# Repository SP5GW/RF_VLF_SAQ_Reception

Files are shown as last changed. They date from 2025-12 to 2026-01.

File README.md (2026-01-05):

<p align="center">

</p> 

# **Odbiór sygnału radiostacji VLF SAQ, Grimeton 17.2 kHz.**

# Wprowadzenie
Pomysł przeprowadzenia odbioru sygnału emitowanego przez szwedzką stację SAQ nadającą spod Geteborga pojawił się przed ponad rokiem. Gdy pierwsza próba odbioru z wykorzystaniem anteny aktywnej miniwhip zakończyła się niepowodzeniem, postanowiłem spróbować ponownie, ale tym razem wykorzystując przedwzmacniacz opisany na stronach Towarzystwa Przyjaciół Grimeton SAQ [1] w połączeniu z anteną magnetyczną.
Wyniki tego eksperymentu oraz wyzwania przed jakimi stanąłem w trakcie jego realizacji opisałem w poniższym artykule.
Źródłem inspiracji do ponownego zmierzenia się z problematyką odbioru sygnałów VLF (Very Low Frequencies) oraz cennych uwag w trakcie przygotowań był kolega Jacek Lipkowski, SQ5BPF. Dziękuję Jacku!

# Antena

## Konstrukcja Anteny

<p align="center">


</p>

*Zdjęcia 1,2: Konstrukcja mechaniczna anteny pętlowej. Indukcyjność anteny to 24.7mH a nie tak jak na rysunku 24.7nH!*

Podczas pierwszej próby odbioru sygnału SAQ posłużyłem się anteną aktywną typu miniwhip podłączoną do odbiornika RSP1A z oprogramowaniem SDRUno [3] konstrukcja tej anteny została opisana w [2], w moim przypadku poziom zakłóceń całkowicie uniemożliwił odbiór sygnałów SAQ czy DCF-77. Dodawanie tłumików prądów błądzących czy poprawa jakości uziemienia stacji odbiorczej nie przyniosły znaczącej poprawy. 

Śledząc tematykę odbioru sygnałów VLF można zauważyć, że najbardziej popularnymi typami anten dla tych długości fal są anteny pętlowe [7][15] i miniwhip [2]. Antena pętlowa reaguje na składową magnetyczną fali radiowej co czyni ją bardziej odporną na zakłócenia przemysłowe, ponadto antena pętlowa cechuje się dużą kierunkowością co pomaga w dalszym zminimalizowaniu zakłóceń przez właściwą orientację anteny względem źródła niepożądanej emisji. Antena typu miniwhip, wykorzystana podczas nieudanej próby, reaguje na składową elektryczną pola elektromagnetycznego, w związku z czym charakteryzuje się wysoką podatnością na zakłócenia, których źródłem mogą być m.in. pobliskie stacje transformatorowe oraz zasilacze impulsowe.

Antenę pętlową zbudowałem na ramie drewnianej w kształcie prostokąta o bokach 80 i 84cm (grubość listwy-kontówki 2cm, krótszy bok zawieszony równolegle do ziemi). Uzwojenie anteny to 80 zwojów drutu o średnicy 0.2mm nawiniętego na plastikowe prowadnice [11] przymocowane do drewnianej ramy (indukcyjność: 24.7mH, rezystancja: 61 omów). Antena nie posiada kondensatora strojeniowego, ponieważ obwód rezonansowy zestrojony na częstotliwość SAQ jest częścią układu przedwzmacniacza. Wymiary anteny są znacząco mniejsze od długości fal z zakresu VLF i dlatego nie są krytyczne. Wybór długości boku został podyktowany głównie walorami praktycznymi takimi jak swoboda przemieszczania anteny.

Należy również podkreślić, że wybór pomiędzy anteną pętlową a aktywną anteną typu miniwhip w dużej mierze zależy od warunków środowiskowych panujących w danej lokalizacji. W obszarach miejskich, charakteryzujących się podwyższonym poziomem zakłóceń, korzystniejszym rozwiązaniem jest zazwyczaj antena pętlowa. Z kolei w środowisku, gdzie poziom zakłóceń jest istotnie niższy, antena miniwhip — ze względu na wysoką czułość — może zapewniać lepsze rezultaty.

Należy zaznaczyć, że w praktyce odbiór sygnału SAQ w obszarze miejskim z wykorzystaniem anteny miniwhip jest jak najbardziej możliwy, pod warunkiem występowania niskiego poziomu zakłóceń w miejscu odbioru.

## Orientacja Anteny względem radiostacji SAQ

Orientacja anteny nie wymaga specjalistycznego sprzętu i może zostać wykonana zgrubnie przy użyciu aplikacji kompasu dostępnej w telefonach komórkowych (pamiętajmy o wyborze opcji "true north" jeśli taka możliwość występuje w wybranym oprogramowaniu). W moim przypadku użyłem GPS Compass dla systemu iOS. Koordynaty lokalizacji anteny odnalazłem na stronie [12], 

<p align="center">
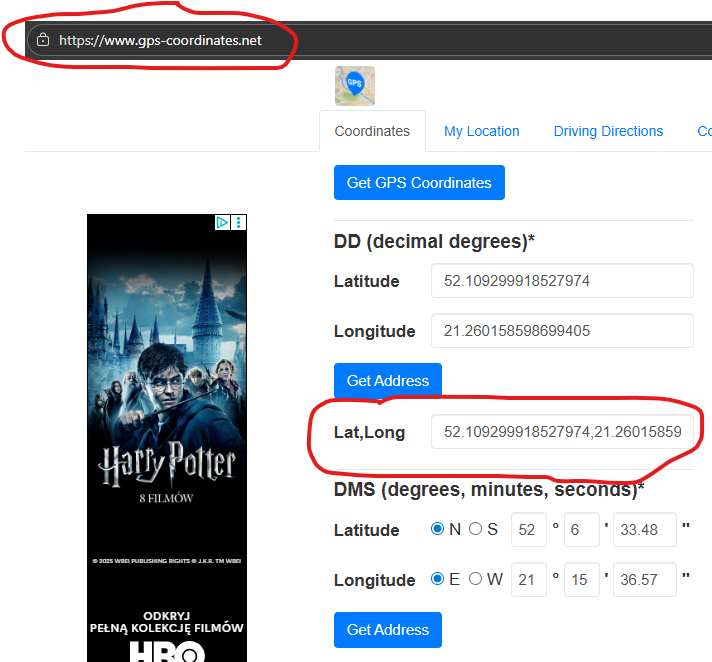
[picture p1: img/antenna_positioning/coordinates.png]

</p>

*Zdjęcie 3: Strona internetowa, która wylicza koordynaty lokalizacji o podanym adresie.*

zaś azymut na który musiałem skierować antenę odczytałem z mapy, którą można wygenerować pod adresem [13].

<p align="center">
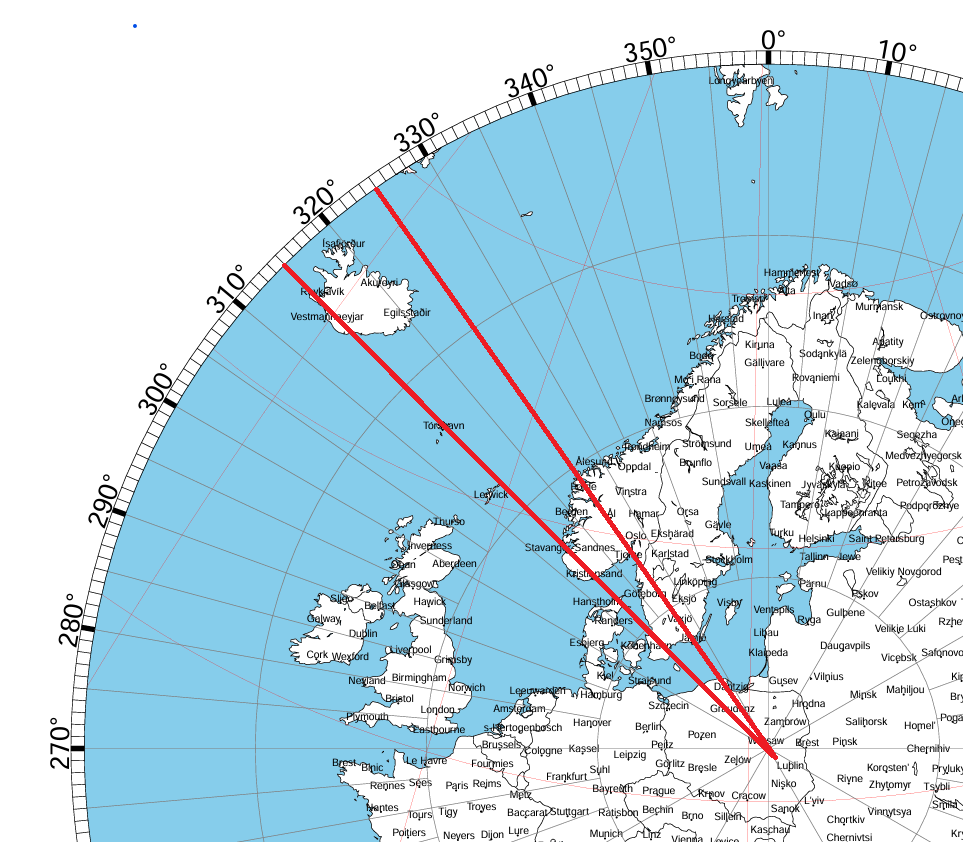
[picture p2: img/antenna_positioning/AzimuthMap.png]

</p>

*Zdjęcie 4: Mapa azymutów z zaznaczonym kierunkiem ustawienia anteny.*
  
W sytuacji gdy w naszej lokalizacji występuje silne źródło zakłóceń kierunkowych warto rozważyć takie ustawienie anteny, które skutkuje najwyższym współczynnikiem sygnału do szumu co nie zawsze będzie tożsame z najwyższym poziomem odbieranego sygnału pożądanego.

# Przedwzmacniacz

## Budowa przedwzmacniacza

Konstrukcja przedwzmacniacza jest oparta o podwójny wzmacniacz operacyjny firmy Analog Devices AD8397 [14] i została opisana na stronach Towarzystwa Przyjaciół Grimeton SAQ [1][6]. 

<p align="center">
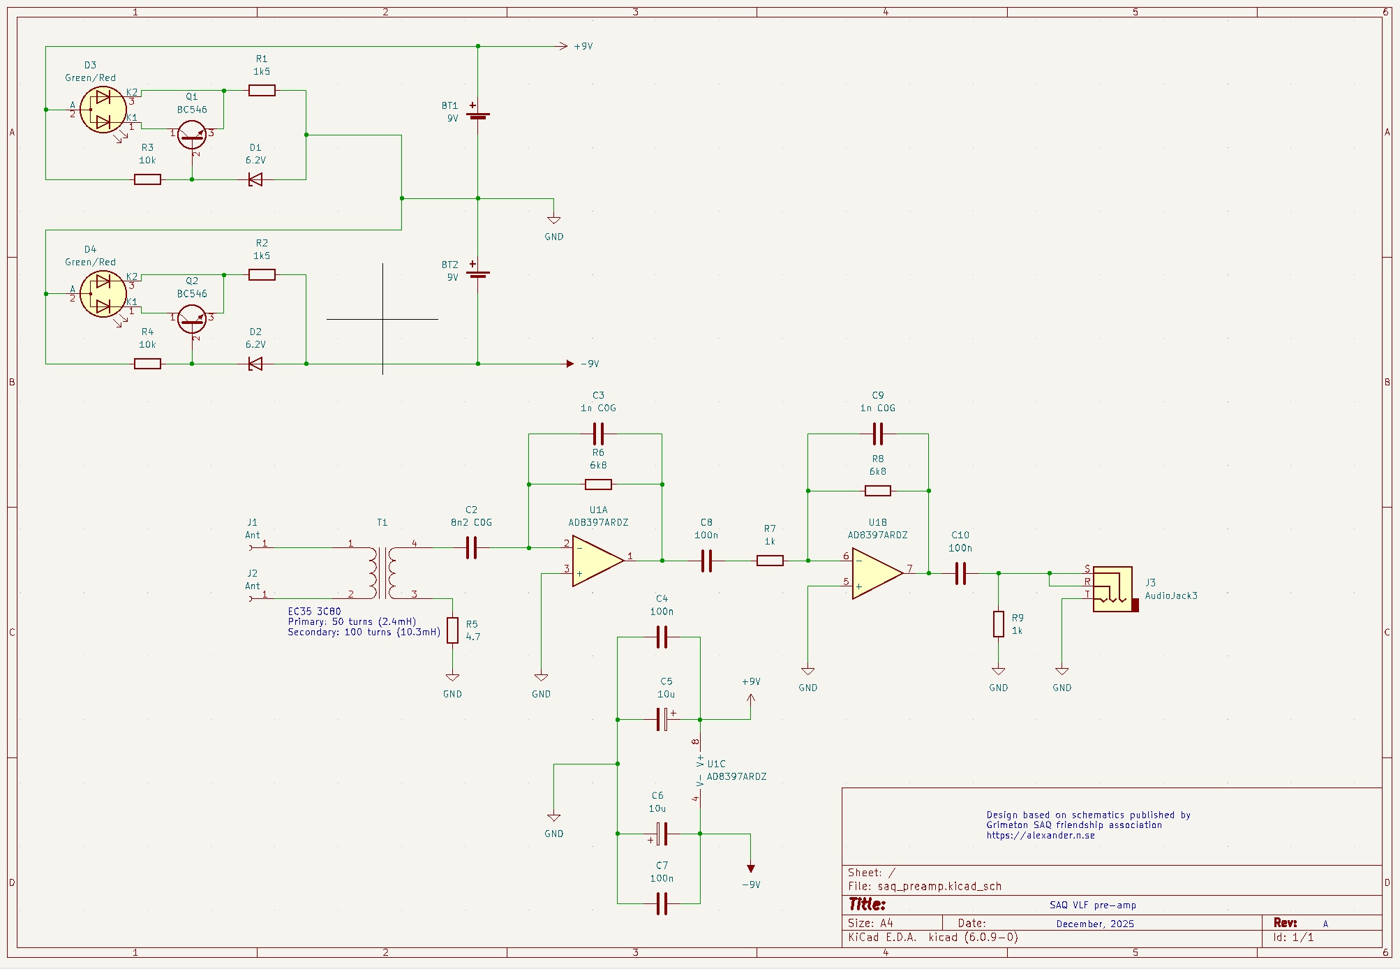
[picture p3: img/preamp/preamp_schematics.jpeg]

</p>

*Zdjęcie 5: Schemat ideowy przedwzmacniacza wraz z układem monitorowania zasilania.*

W ramach projektu układ bazowy uzupełniono o następujące elementy:
1) Kondensatory odsprzęgające 1uF zostały zastąpione parami kondensatorów 100n oraz 10u.
2) Uzwojenie wtórne transformatora wejściowego T1 zwiększono z 90 do 100 zwojów drutu o średnicy 0.2mm.
3) Dodano wyjście SMA-C w celu łatwiejszego przyłączenia odbiornika SDR takiego jak np. RSP1A [3]. W przypadku współpracy przedwzmacniacza z odbiornikiem SDR nie jest wymagany dodatkowy tłumik sygnału, funkcję tę realizuje filtr górnoprzepustowy utworzony przez elementy C10 (100 nF) oraz rezystor R9 (1 kΩ). Częstotliwość graniczna tego filtra ulega przesunięciu w kierunku niższych częstotliwości w wyniku przyłączenia odbiornika SDR, którego impedancja wejściowa jest dużo niższa od rezystancji R9 (oraz impedancji wejściowej karty dźwiękowej). W efekcie dla pasma VLF poziom sygnału wyjściowego z przedwzmacniacza obniża się o około 10dB w stosunku do odbioru z wykorzystaniem karty dźwiękowej.
4) Baterie 4V zastąpiono bardziej dostępnymi bateriami 9V. Zasilanie bateryjne pozwala na obniżenie poziomu zakłóceń docierających do wzmacniacza.
5) Dodano proste układy monitorujące stan baterii oparte o tranzystor BC546 oraz diody zabezpieczające przed niewłaściwą polaryzacją. W przypadku obniżenia napięcia zasilania poniżej 8,11V kolor diod LED D3/D4 zmienia się z zielonego na czerwony. Wykorzystany układ monitorujący jest modyfikacją rozwiązania opisanego przez Einara Abella na portalu EDN [9].

<p align="center">
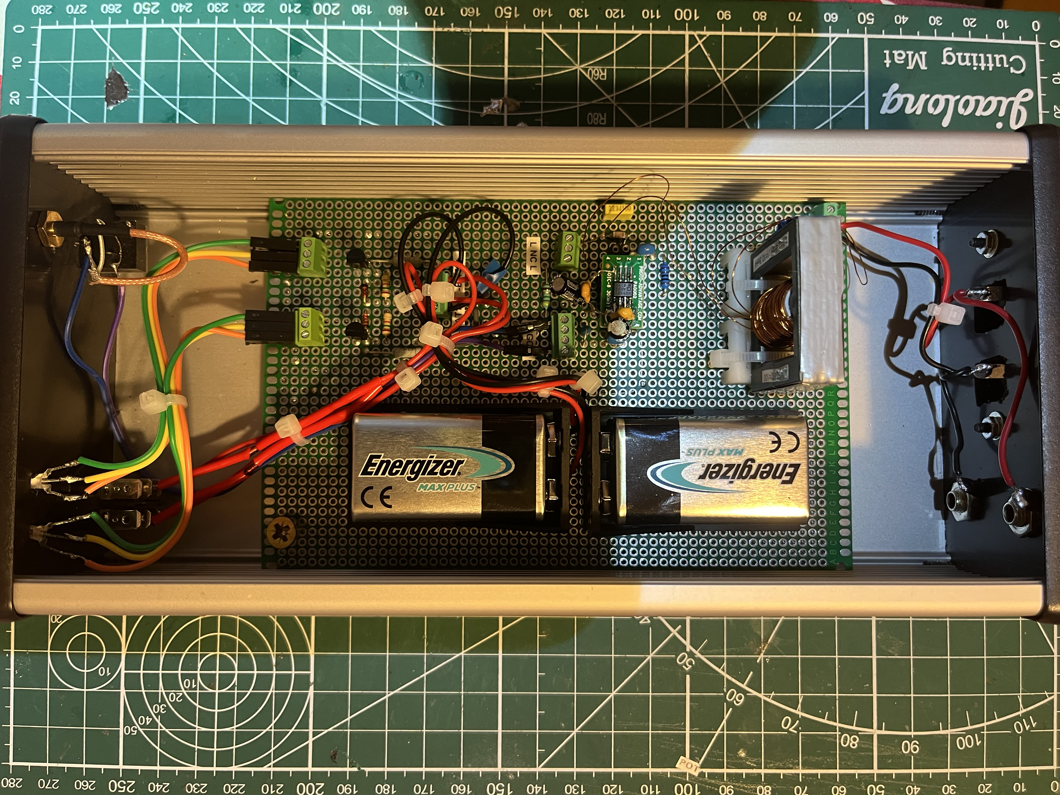
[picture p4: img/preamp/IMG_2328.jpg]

</p>
<p align="center">
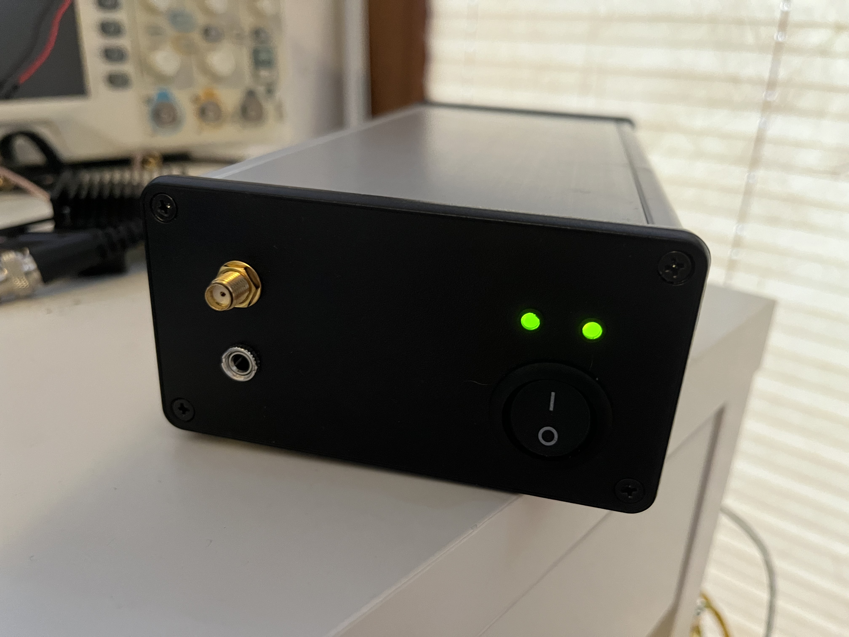
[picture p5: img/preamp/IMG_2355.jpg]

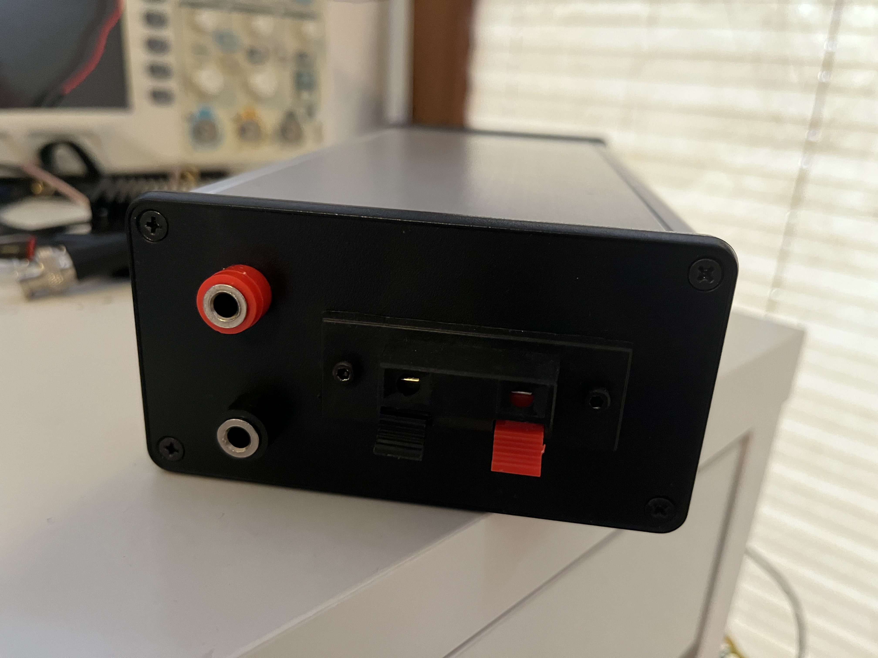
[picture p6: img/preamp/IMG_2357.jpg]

</p>

*Zdjęcia 6,7,8: Konstrukcja mechaniczna układu przedwzmacniacza.*

Intuicja sugeruje, że przedwzmacniacz powinien być umieszczony możliwie najbliżej anteny i połączony z nią jak najkrótszym przewodem. W przeprowadzonych przeze mnie testach długość przewodu łączącego antenę z przedwzmacniaczem, jak również odległość samego przedwzmacniacza od anteny, nie miały jednak zauważalnego wpływu na jakość odbioru.

## Strojenie przedwzmacniacza

Do zestrojenia wzmacniacza na częstotliwość SAQ 17,2 kHz nie jest wymagane użycie specjalistycznej aparatury pomiarowej. Oczywiście możliwe jest wykorzystanie generatora funkcyjnego oraz oscyloskopu, jednak wystarczającą dokładność zapewnia obserwacja poziomu wzmocnienia szumów tła pochodzących z wejścia przedwzmacniacza pozostawionego bez podłączonej anteny. Jeżeli maksimum poziomu szumów występuje w pobliżu częstotliwości SAQ, można uznać, że układ został prawidłowo zestrojony. Należy przy tym uwzględnić, że obwód rezonansowy charakteryzuje się stosunkowo wąskim pasmem przenoszenia — w przedstawionej implementacji wynoszącym około 210 Hz — co wymaga dość precyzyjnego dostrojenia układu.

W przypadku strojenia przy użyciu generatora funkcyjnego należy pamiętać o właściwym odseparowaniu generatora od układu przedwzmacniacza, aby w trakcie strojenia częstotliwość rezonansu nie uległa zmianie w wyniku przełączania źródła sygnału pomiędzy generatorem a anteną. Dobrym rozwiązaniem jest użycie krótkiej anteny podłączonej do wyjścia generatora (dwa niepołączone ze sobą kable o długości ok. 10-15cm, generator musi znajdować się w pobliżu przedwzmacniacza) lub przyłączenie generatora do układu przedwzmacniacza przez rezystor o dużej oporności np. 100 kiloomów. 

<p align="center">
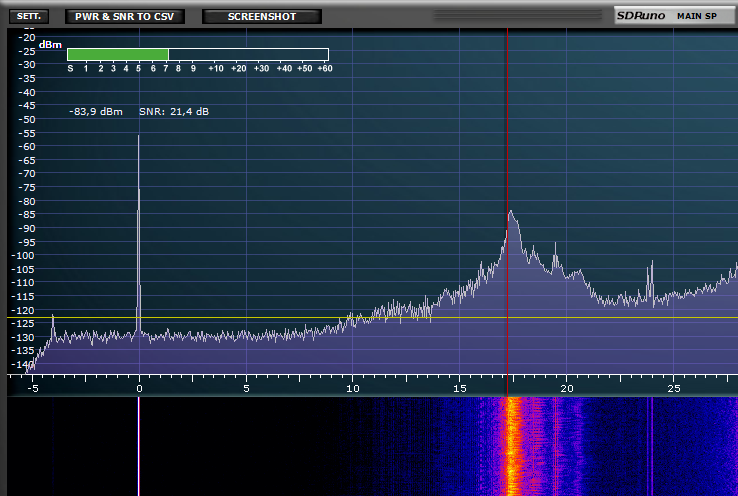
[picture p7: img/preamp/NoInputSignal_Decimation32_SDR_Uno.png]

</p>

*Zdjęcie 9: Widmo sygnału na wyjściu przedwzmacniacza z odłączoną anteną.*

### Parametry przedwzmacniacza

<p align="center">
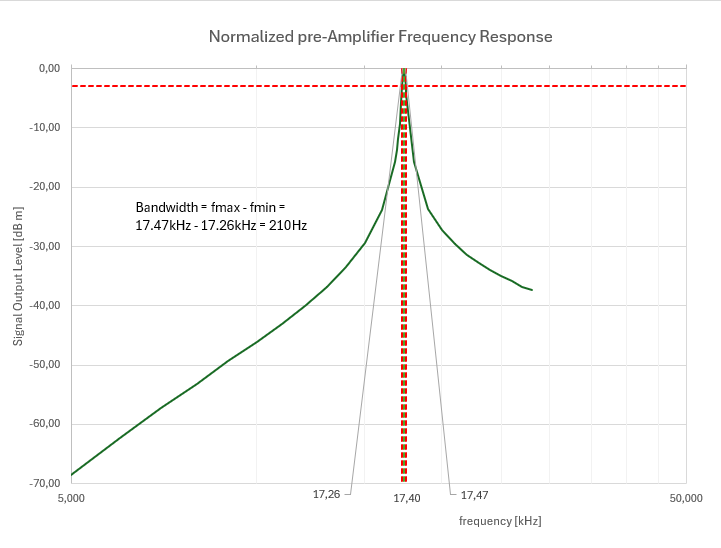
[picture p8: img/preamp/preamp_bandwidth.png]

</p>

*Zdjęcie 10: Pasmo przenoszenia przedwzmacniacza wyznaczone na podstawie rzeczywistych danych pomiarowych.*

<p align="center">
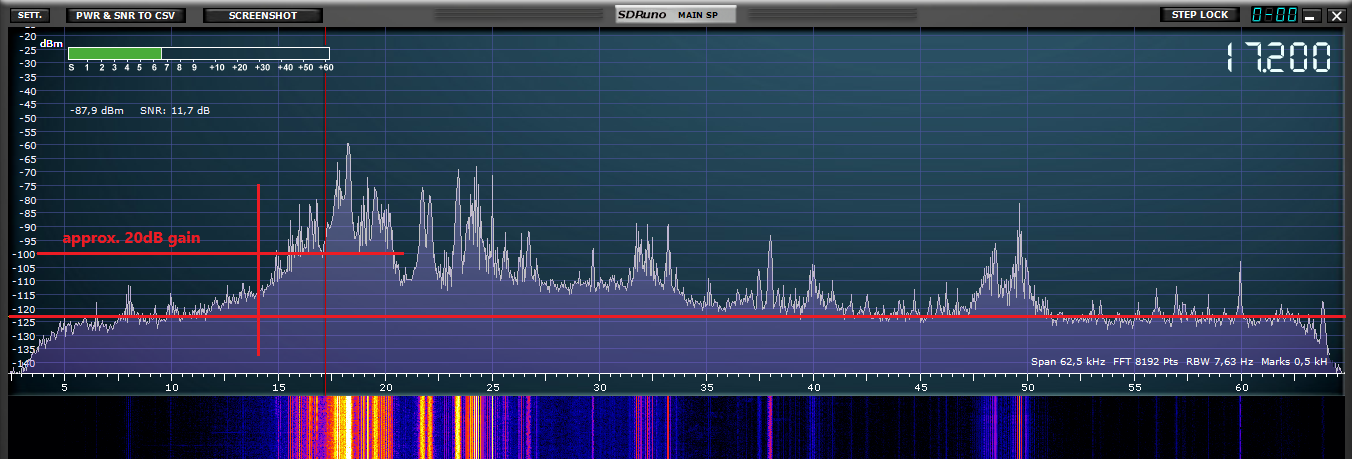
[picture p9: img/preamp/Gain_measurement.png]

</p>

*Zdjęcie 11: Oszacowanie wzmocnienia układu w obszarze rezonansu obwodów wejściowych.*

Jak można zauważyć w oparciu o powyższe ilustracje, wzmacniacz nie wprowadza tłumienia, poza pasmem przenoszenia obwodu rezonansowego, co umożliwia odbiór stacji innych niż SAQ nadających na częstotliwościach nawet z zakresu fal długich. Prezentowany układ pozwolił np. na stabilny odbiór sygnałów synchronizacji czasu NPL (60 kHz) oraz DCF-77 (77.5 kHz). W tej samej lokalizacji odbiór tych sygnałów był bardzo niestabilny, a często nawet niemożliwy przy użyciu anteny typu miniwhip czy "random wire" (w tym konkretnym przypadku długość elementu odbiorczego wynosiła ok. 13m).

## Potencjalne problemy do uniknięcia

1) Brak kondensatorów odsprzęgających w torze zasilania może prowadzić do wzbudzania się wzmacniaczy operacyjnych, a w skrajnych przypadkach do ich uszkodzenia wskutek nadmiernego nagrzewania. Zjawisko to może występować poza zakresem częstotliwości VLF i pozostawać niewidoczne zarówno na oscyloskopie, jak i na wodospadzie odbiornika SDR skonfigurowanego do monitorowania pasma VLF (w ten sposób utraciłem jeden z układów na kilka dni przed planowaną emisją).

2) Strojenie za pomocą generatora funkcyjnego bezpośrednio przyłączonego do układu wejściowego przedwzmacniacza  prowadzi do zmiany charakterystyki obwodu i w efekcie przesunięcia częstotliwości rezonansu w porównaniu do sytuacji, w której obciążeniem uzwojenia pierwotnego jest antena. Jest to podyktowane faktem, że impedancja uzwojenia pierwotnego z szeregowo przyłączoną niską impedancją generatora sygnałowego (o charakterze mocno rezystancyjnym) istotnie wpływa na reaktancję obwodu wejściowego, podwyższając jego częstotliwość rezonansową. Początkowo nie byłem świadomy występowania tego zjawiska. W konsekwencji, w celu uzyskania maksimum wzmocnienia przy częstotliwości 17,2 kHz przy podłączonym generatorze, do kondensatora C2 (8,2 nF) dołączyłem równolegle dodatkowy kondensator o pojemności 22 nF. Zarówno przedstawiona poniżej symulacja, jak i wyniki pomiarów wskazują, że po odłączeniu generatora i zastąpieniu go anteną rzeczywista częstotliwość rezonansowa obwodu ulegała istotnemu obniżeniu.

<p align="center">
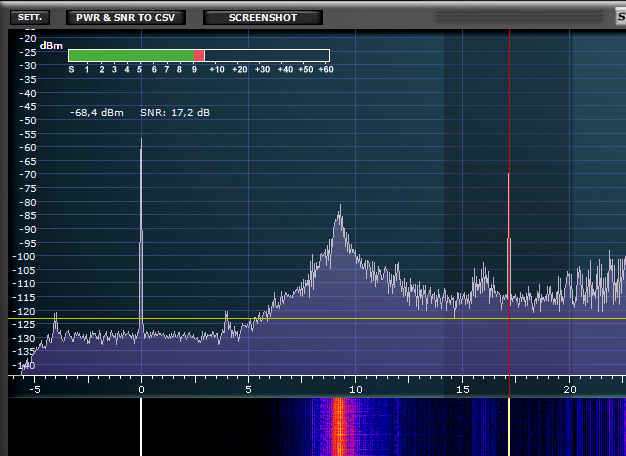
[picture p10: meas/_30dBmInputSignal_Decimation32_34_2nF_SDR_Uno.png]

</p>

*Zdjęcie 12: Widmo sygnału z widocznym przesunięciem "w dół" pasma przenoszenia obwodu wejściowego względem markera SAQ 17.2 kHz. Kondensator w obwodzie rezonansowym posiada wartość 8.2nF + 22nF. Przedwzmacniacz pozostaje odłączony od generatora lub jest do niego przyłączony poprzez szeregowy rezystor 100 kiloomów.*

<p align="center">
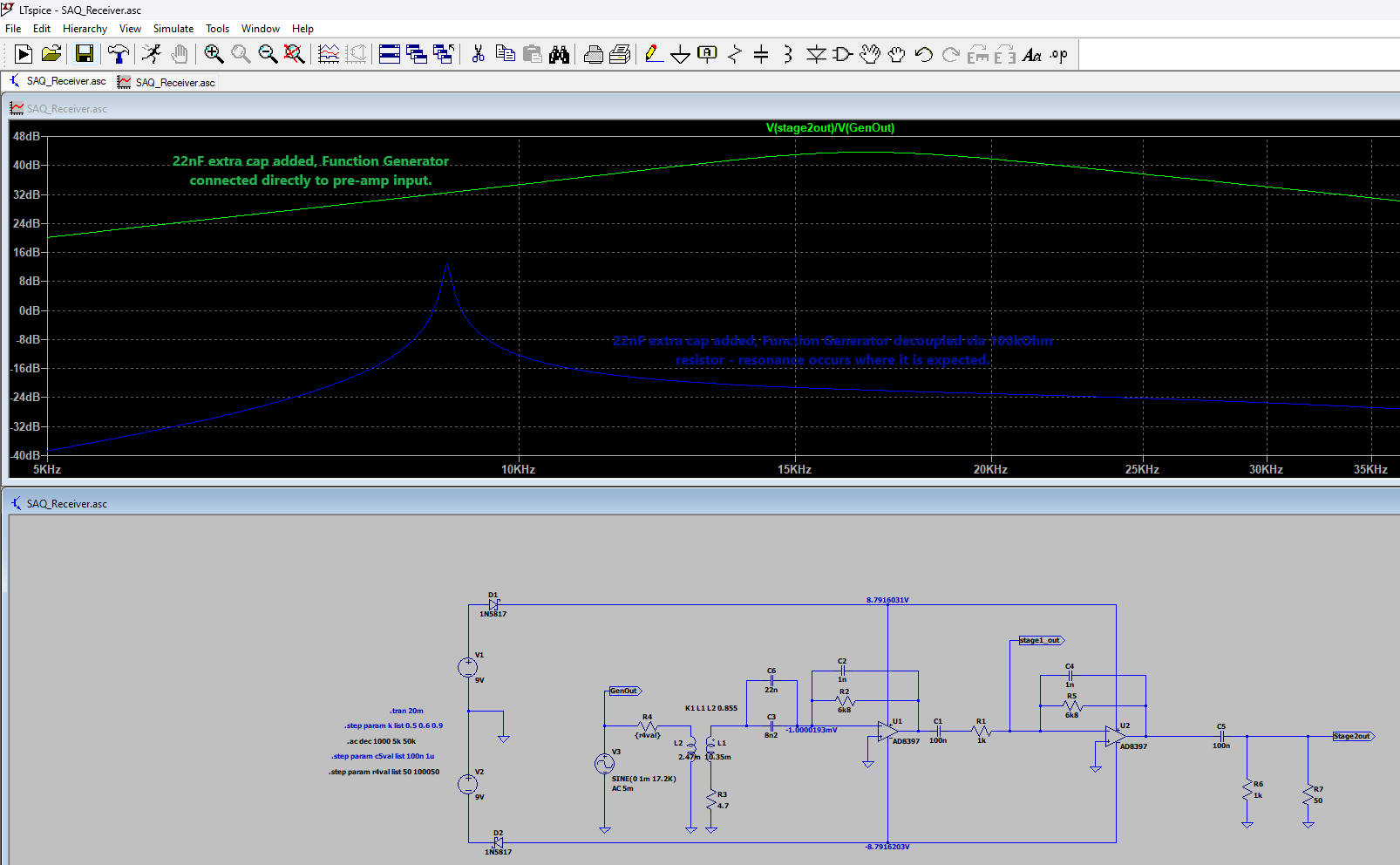
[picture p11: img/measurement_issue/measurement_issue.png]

</p>

*Zdjęcie 13: Symulacja w LTSpice przypadku ze Zdjęcia 12*
  
Usunięcie dodatkowego kondensatora 22nF, pozwoliło na uzyskanie poprawnego zestrojenia układu na częstotliwość 17.2 kHz z przyłączoną anteną.

<p align="center">
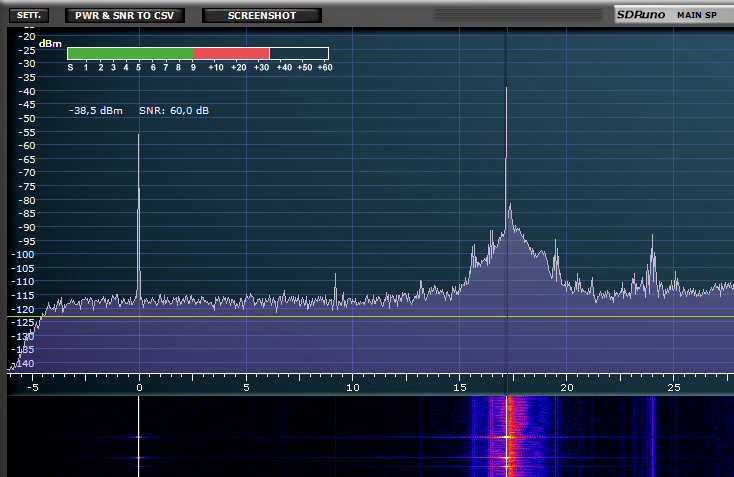
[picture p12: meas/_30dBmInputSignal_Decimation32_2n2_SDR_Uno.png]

</p>

*Zdjęcie 14: Widmo sygnału z prawidłowo zestrojonym obwodem wejściowym (marker SAQ 17.2 kHz umieszczony centralnie w paśmie przenoszenia obwodu wejściowego). Kondensator w obwodzie rezonansowym posiada wartość 8.2nF*

Podczas testów sygnał SAQ był symulowany przez nośną z generatora sygnałowego do którego wyjścia przyłączony został przewód pełniący rolę prostej anteny. Poziom sygnału wyjściowego generatora w tym scenariuszu testowym był ustawiony na maksymalną wartość, a generator znajdował się w bezpośrednim sąsiedztwie przedwzmacniacza. Takie same warunki pomiarowe można uzyskać podłączając generator funkcyjny poprzez rezystor 100 kiloomów.

# Oprogramowanie

Układ przedwzmacniacza może współpracować zarówno z kartą dźwiękową PC jak też odbiornikiem SDR zdolnym do odbioru sygnałów w zakresie VLF (np. z modułem RSP1A firmy SDRPlay). 
W przypadku odbioru z wykorzystaniem karty dźwiękowej bardzo dobrze sprawdziło się oprogramowanie SAQrx dostępne na stronie Towarzystwa Przyjaciół Grimeton SAQ [1]:

<p align="center">
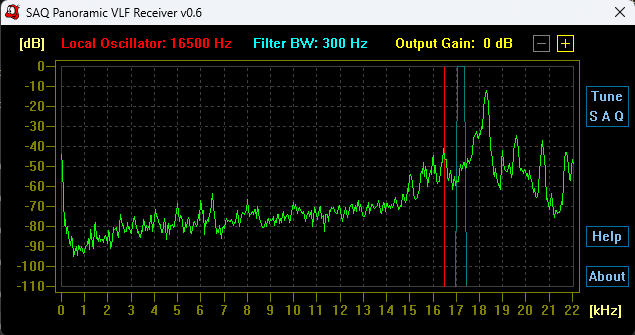
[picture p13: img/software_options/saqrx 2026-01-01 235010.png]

</p>

*Zdjęcie 15: Odbiór sygnałów VLF przy pomocy programu SAQrx (wyjście przedwzmacniacza jest podłączone do wejścia liniowego karty dźwiękowej komputera)*

oraz oprogramowanie Spectrum Lab autorstwa Wolfganga Bueschera, DL4YHF:

<p align="center">
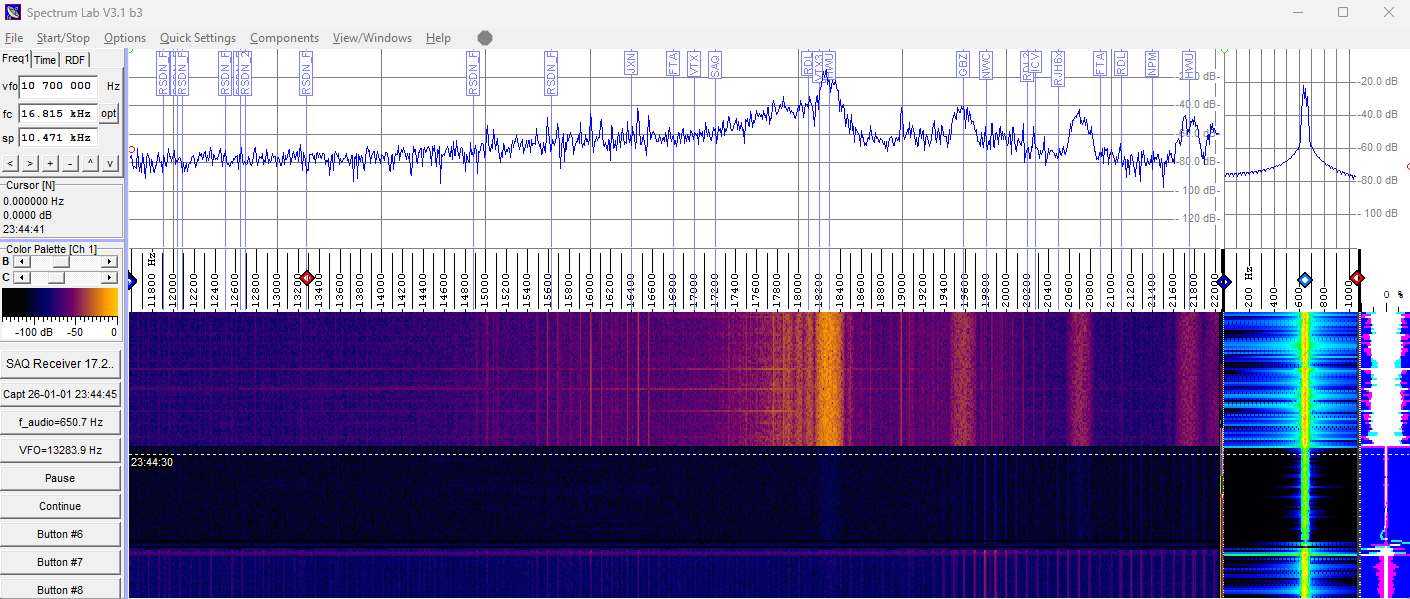
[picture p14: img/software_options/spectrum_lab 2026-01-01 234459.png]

</p>

*Zdjęcie 16: Odbiór sygnałów VLF przy pomocy programu Spectrum Lab (wyjście przedwzmacniacza jest podłączone do wejścia liniowego karty dźwiękowej komputera)*

Zaletą pakietu Spectrum Lab jest dostępność funkcji wodospadu.

W przypadku odbioru z wykorzystaniem układu SDR wybór oprogramowania jest bardzo zależny od wykorzystywanej platformy sprzętowej. W przypadku RSP1A, najlepszym wyborem wydaje się oprogramowanie rozwijane przez dostawcę sprzętu czyli program SDRUno.

<p align="center">
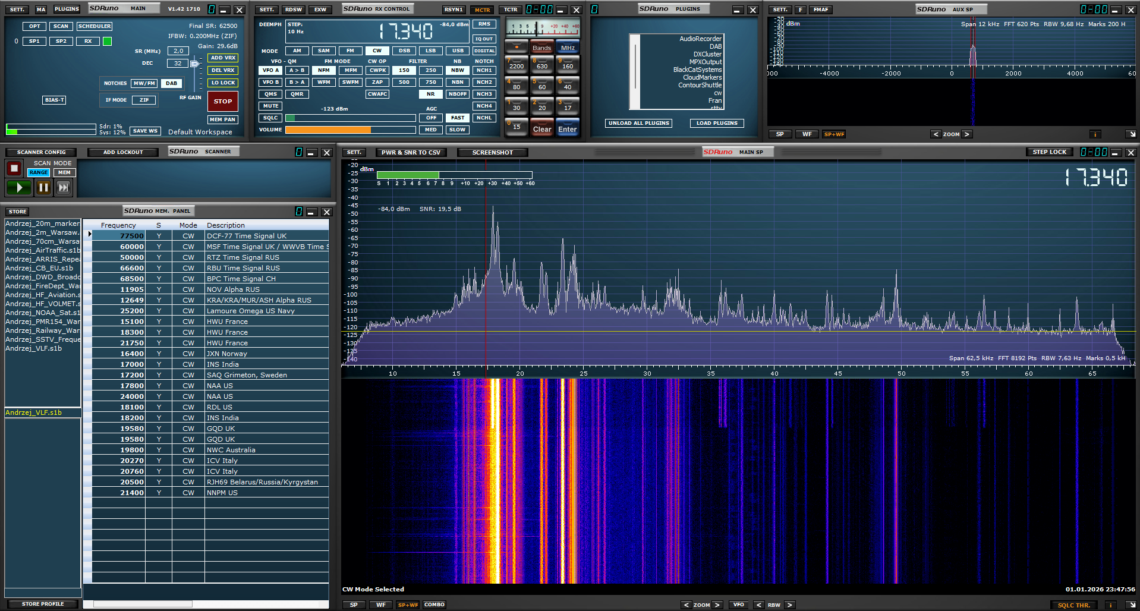
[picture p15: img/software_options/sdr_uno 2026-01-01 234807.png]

</p>

*Zdjęcie 17: Odbiór sygnałów VLF przy pomocy programu SDRUno (wyjście przedwzmacniacza jest podłączone do wejścia antenowego odbiornika SDR RSP1A firmy SDRPlay)*

Jeśli zależy nam na maksymalnym obniżeniu poziomu zakłóceń w miejscu odbioru, wówczas należałoby rozważyć zastąpienie komputera PC oraz odbiornika SDR dobrej jakości dyktafonem z wejściem liniowym oraz wysoką częstotliwością próbkowania takim jak np.: Zoom H1 Essential [10]. W takiej sytuacji wskazany jest również odbiór z obszaru o niskim poziomie zakłóceń.

# Jakość odbioru a typ anteny

Ze względu na fakt, że wielu użytkowników prowadzi odbiór w środowisku o zbliżonym poziomie zakłóceń do tych które występują w mojej lokalizacji, zdecydowałem się na wykonanie i prezentację pomiarów dla anteny pętlowej oraz anteny typu miniwhip, zainstalowanych w niewielkiej odległości od siebie.

Sposób zawieszenia porównywanych anten został pokazany na zdjęciu poniżej. Do testów wykorzystano antenę miniwhip konstrukcji Antona Gavrilova, RA0SMS, o porównywalnych parametrach do klasycznego miniwhip'a opracowanego przez Nico Veth'a PA0NHC.

<p align="center">

</p>

*Zdjęcie 18: Lokalizacja porównywanych anten*

## Wyniki dla anteny pętlowej

Widma odbieranego sygnału w paśmie VLF, oraz dla częstotliwości DCF-77:

<p align="center">
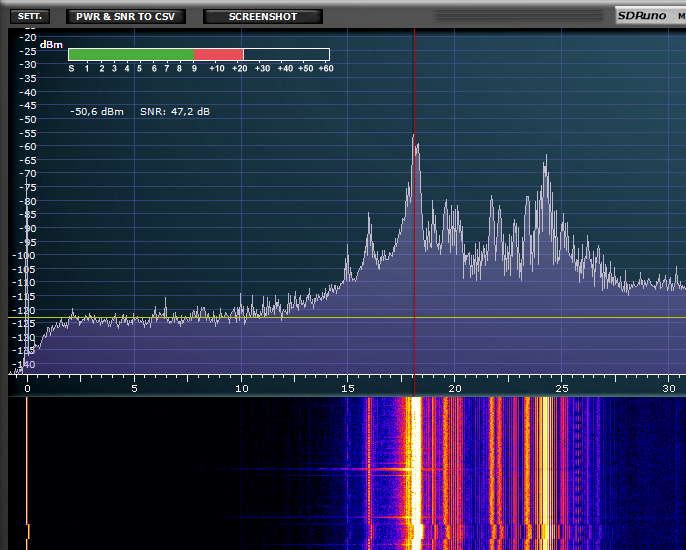
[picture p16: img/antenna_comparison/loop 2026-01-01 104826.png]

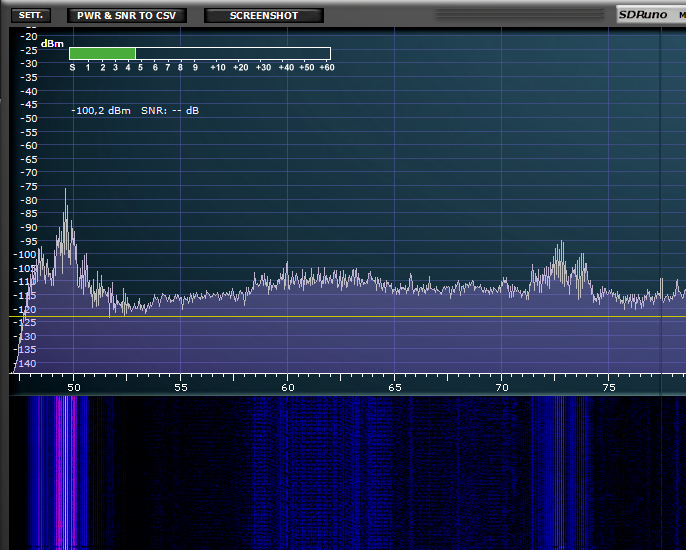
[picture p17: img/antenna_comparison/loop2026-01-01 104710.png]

</p>

*Zdjęcia 19,20: Od lewej: Widmo sygnału dla pasma VLF oraz częstotliwości DCF-77. W obydwu przypadkach do odbioru wykorzystywana jest antena pętlowa.*

## Wyniki dla anteny miniwhip

Widma odbieranego sygnału w paśmie VLF, oraz dla częstotliwości DCF-77:

<p align="center">
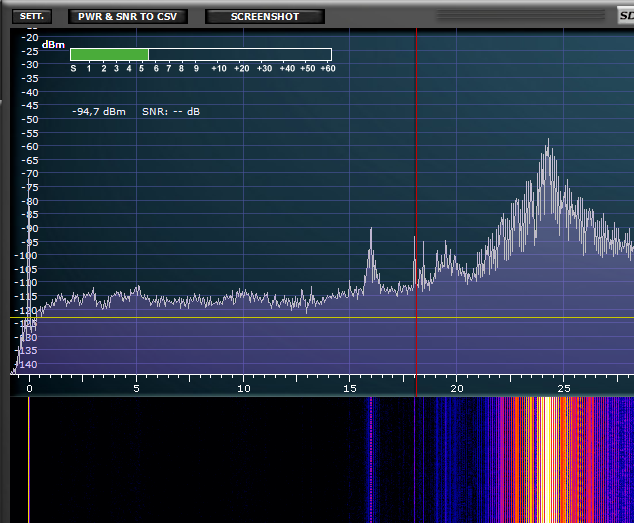
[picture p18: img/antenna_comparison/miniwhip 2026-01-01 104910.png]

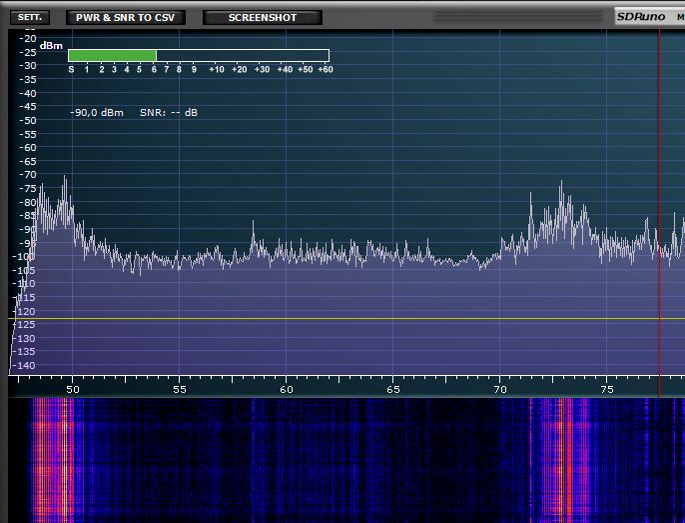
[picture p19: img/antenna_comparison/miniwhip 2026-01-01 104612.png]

</p>

*Zdjęcia 21,22: Od lewej: Widmo sygnału dla pasma VLF oraz częstotliwości DCF-77. W obydwu przypadkach do odbioru wykorzystywana jest antena miniwhip.*

W moim przypadku, odbiór sygnałów w paśmie VLF oraz sygnału synchronizacji czasu DCF-77 był możliwy wyłącznie z wykorzystaniem przedwzmacniacza wraz z anteną pętlową. 

Należy jeszcze raz podkreślić, że porównanie wykonano w obszarze miejskim o wysokim poziomie zakłóceń, generowanych m.in. przez zasilacze impulsowe, stację transformatorową zlokalizowaną w promieniu do 80 m od anten oraz stację bazową telefonii komórkowej znajdującą się w odległości ok. 100 m.

# Podsumowanie

Po roku przygotowań udało się odebrać sygnał stacji SAQ Grimeton. Oprócz samej satysfakcji z odbioru, projekt ten umożliwił mi zdobycie cennego doświadczenia oraz wymianę wiedzy z innymi pasjonatami fal bardzo długich.

Ze względu na regularne emisje stacji SAQ oraz możliwość całorocznych nasłuchów w paśmie 10–250 kHz, opisane rozwiązanie może stanowić dobrą bazę do dalszych eksperymentów.

73 Andrzej SP5GW

<p align="center">
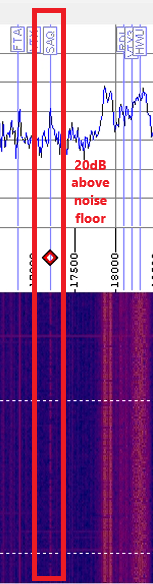
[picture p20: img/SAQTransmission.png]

</p>

*Zdjęcie 23: Odebrany sygnał SAQ 17.2 kHz zobrazowany w programie Spectrum Lab.*

# Źródła

[1] Towarzystwo Przyjaciół Grimeton SAQ, https://alexander.n.se/

[2] Antena miniwhip, https://github.com/SP5GW/MiniWhip_Antenna

[3] SDR Play, https://www.sdrplay.com/

[4] Oprogramowanie Spectrum lab autorstwa Wolfganga Bueschera, DL4YHF https://www.qsl.net/dl4yhf/spectra1.html

[5] Ustawienia programu Spectrum Lab dla SAQ  https://www.qsl.net/dl4yhf/speclab/vlf_rcvr.htm

[6] Opis przedwzmacniacza VLF, https://alexander.n.se/en/the-radio-station-saq-grimeton/lyssna-pa-saq/

[7] Opis działania anteny pętlowej autorstwa Williama E. Paynea, N4YWK, http://www.vlf.it/octoloop/rlt-n4ywk.htm

[8] Portal dla entuzjastów VLF, http://www.vlf.it/

[9] Układ monitorowania zasilania, Einar Abell, EDN 2 Marca 2015, https://www.edn.com/voltage-indicator-transitions-between-colours/

[10] Strona producenta Zoom, https://www.zoom-europe.com/pl/podreczne-dyktafony/zoom-h1e

[11] Uchwyty kablowe Diall typu STM 4,8 mm, https://www.castorama.pl/

[12] Portal umożliwiający odszukanie koordynat danej lokalizacji,  https://www.gps-coordinates.net/

[13] Portal umożliwiający generowanie map azymutowych autorstwa Thomasa Epperly, NS6T, https://ns6t.net/azimuth/

[14] Nota katalogowa układu AD8397 oraz model LTSpice, https://www.analog.com/en/products/ad8397.html

[15] Praktyczny opis budowy strojonej anteny magnetycznej, https://physicsopenlab.org

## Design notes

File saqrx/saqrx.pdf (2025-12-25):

# SAQrx

A VLF Receiver with Panoramic Tuning

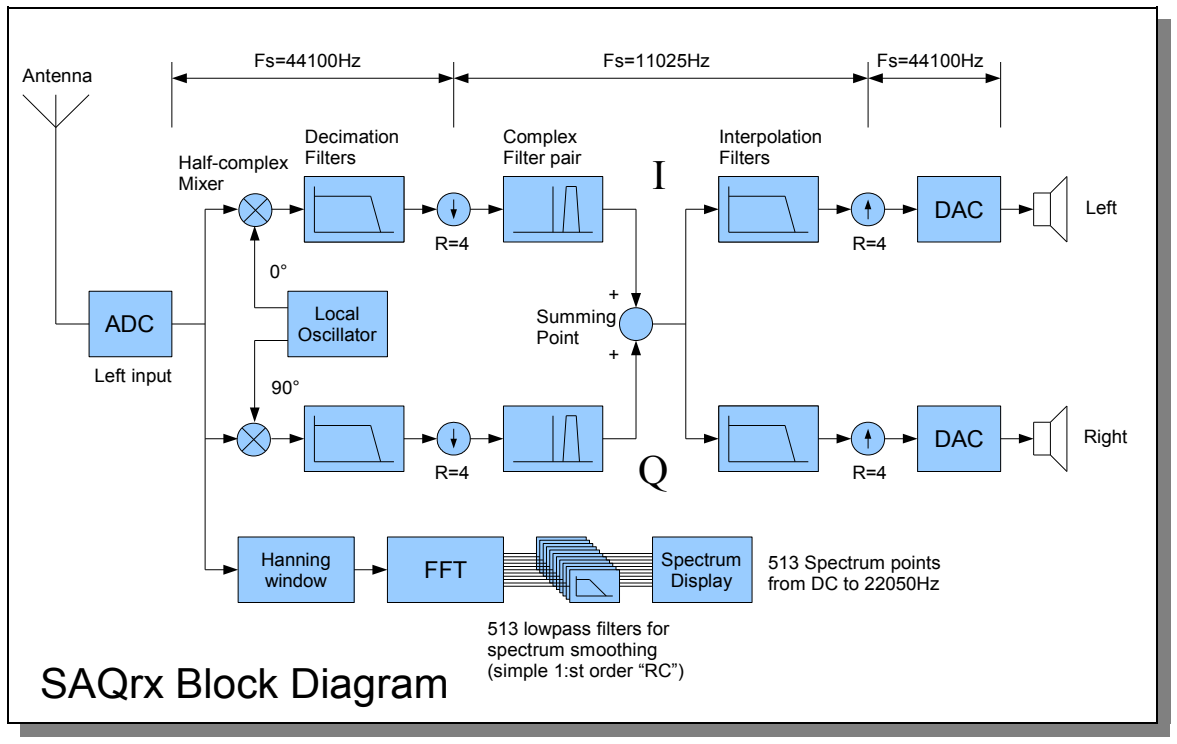
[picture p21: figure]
ADC; Local Oscillator; DAC; Half-complex Mixer; Decimation Filters; Complex Filter pair; Interpolation Filters; Summing Point; Antenna; Left; Right; FFT; Spectrum Display; 513 Spectrum points from DC to 22050Hz; 513 lowpass filters for spectrum smoothing (simple 1:st order “RC”); Left input; SAQrx Block Diagram; Hanning window

RECEIVER

SAQrx is built almost like the schoolbook example of a phasing method SSB receiver, the main difference is that SAQrx is held together by DSP software instead of solder. Below is an attempt to describe the signal flow through SAQrx:

The input signal is sampled at Fs=44100Hz and fed to a half-complex mixer where the signal is mixed (multiplied) with a quadrature local oscillator signal, cos(ωLO * t) for the I branch and sin(ωLO * t) for the Q branch. The resulting complex I/Q signal may contain both positive and negative frequencies. A single frequency I/Q signal can be thought of as a rotating vector in the I/Q plane where the length of the vector is the signal amplitude and the rotation is the signal frequency. If the input signal has a higher frequency than the LO, the I/Q vector will rotate clockwise and vice versa. An input signal at the same frequency as the LO (zero beat) will produce a still standing vector whose “pointing direction” in the I/Q plane depends on the phase relationship between the input signal and the LO.

RECEIVER (cont'd)

The I/Q signal from the complex mixer is passed through two equal lowpass filters (decimation filters). These are 64-tap FIR filters that are flat from DC to 3000Hz. The filter stopband is about -90dB at 5512Hz which “happens” to be Fs/8. The purpose of these filters is to band-limit the I/Q signal to less than half the new sampling rate in order to avoid aliasing (Nyquist). In other words, only those antenna input signals that are within +/-3000Hz of the LO frequency will pass through the decimation filters. The decimation filters guarantee that the I/Q signal contains no frequency components above 5512Hz so we can safely decimate (reduce the sampling rate) by a factor of four (R=4) to 11025Hz. The FIR buffers of the decimation filters are filled at Fs=44100Hz but they are only “computed” at the output rate, Fs=11025Hz. The reason for decimation is to reduce the computational load. Not only is the FIR filter computing rate reduced, the filters can have less taps too without sacrificing performance!

Next step is the complex filter which provides the main selectivity in the SAQrx receiver. Both halves, I and Q, are initially designed as two exactly equal lowpass FIR filters having half the desired SSB bandwidth (DC to Fbw/2). This results in a passband +/-Fbw/2 around DC (zero beat) which is not exactly what we want. The receiver would sound like a direct conversion receiver with equal response either side of zero beat. So, in order to shift the passband center away from DC to a comfortable CW pitch, and true single sided reception, we multiply the coefficient sets for the two filters by cos(Foffs) and sin(Foffs), respectively, where Foffs is the desired shift from DC. The resulting (complex!) filter response now looks as shown in the complex filter boxes in the block diagram where the vertical line corresponds to zero beat. SAQrx actually contains three selectable complex filters although only one is shown in the block diagram.

Classic (hardware) phasing receiver designs often use a wideband phasing network that puts the relative phase of the I and Q signals 90 degrees apart, over the whole audio bandwidth of interest, and then use some kind of bandpass filter after the “Summing Point”. The 90° phasing network can be made as a FIR filter in DSP (Hilbert transformer) but I think the complex filter approach is more elegant since it “kills two birds with one stone” - bandpass filtering and phase shifting.

The I and Q components from the complex filters are added in the “Summing Point”. This point is where the actual sideband cancellation occurs. SAQrx is “wired” for USB reception. If you want LSB just subtract I from Q (change sign on one of them), or swap the I and Q lines before the complex filter or swap the two LO outputs. A two-phase AC motor is a good analogy – just swap the two phases anywhere along the powerline and the motor will run backwards ;-)

The signal from the summing point is a real (“single-wire”) signal almost ready for listening, the only remaining problem is to step up the sampling frequency from 11025Hz to 44100Hz.
This step-up is necessary since the DAC runs at the same speed as the ADC. This is accomplished in an interpolation filter. SAQrx happens to have two identical interpolation filters although a single filter would be enough since both filters carry exactly the same signal. The reason for using two filters is that I have plans for playing with “binaural pseudo-stereo” experiments in the future ;-)

The interpolation filters use exactly the same FIR coefficients as the decimation filters, they have exactly the same frequency response, but they are implemented differently to save processing time. The output of the interpolation filters is computed at Fs=44100Hz while the input is fed with 11025 signal samples each second, interleaved with three zeroes between each signal sample. The fact that three out of four input samples are zero makes it possible to use a trick. Even though the filter has 64 taps (theoretically), only 16 taps (multiply-and-accumulate operations) have to be computed at each 44100Hz sampling instant. In addition, the FIR data buffer size can be reduced to 16. The FIR coefficients are split into four groups that are used cyclically when computing the filter output.

RECEIVER (cont'd)

Oops! I forgot to draw the 0..50dB gain control in the block diagram. The signal is multiplied by a constant, 1 to 316, between the interpolation filters and the DACs. You'll have to imagine this...

SPECTRUM DISPLAY

Every input sample from the ADC is stored in the FFT input buffer. Whenever the buffer gets filled, the entire 1024 sample chunk in the buffer is multiplied by a Hanning window function in order to reduce the sidelobes in the spectrum plot. The windowed data chunk is then passed to the “real input” FFT routine which takes 1024 real (“single-wire”) input samples and generate a 513 point complex (I/Q) output spectrum, ranging from DC to 22050Hz, in the FFT output buffers. The audio processing and the screen drawing operations run in different and asynchronous threads; the FFT is run about twice as often as the screen redraw function, which runs at approximately 50ms intervals, so more than half of the FFT output is wasted. This is not a serious problem, just a bit ugly. You can see that the spectrum graph looks more “lively” when the filter passband is beeing dragged with the mouse because the screen is then updated continously to make the movement look smoother.

Anyway, the screen drawing routine sets a flag when it has finished the spectrum plot. If this flag is set at the end of the FFT calculation, the audio thread will compute the amplitude spectrum. We are not interested in the relative phase of each FFT frequency “bin”, only the absolute amplitude, so we use Pythagoras on each complex frequency “bin”: Amplitude = I
2Q

2
- . These 513 amplitude
points are then individually lowpass filtered to get a smoother and less “nervous” display. These filters are very simple, they are actually the DSP equivalent of simple first order RC filters. After smoothing, the amplitude points are stored in a buffer that is read by the screen drawing routine where the amplitudes are converted to dB and scaled for screen output.

DEVELOPMENT TOOLS

IDE/compiler: DEV-C++, version 4.9.9.2, www.bloodshed.net
Soundcard interface: Portaudio, version 18, www.portaudio.com
FIR filter design: ScopeFIR version 3.7a, www.iowegian.com

I use "PortAudio" for audio I/O because it is extremely simple to use compared to accessing window$'s messy multimedia functions directly. Portaudio's application program interface (API) is fully described in the file portaudio.h. The included version of Portaudio uses the “classic” window$ MME interface only, there is no support for WDM-KS, ASIO etc. PortAudio source code is freely available on the web but you don't have to download it; the SAQrx zip file contains all Portaudio files needed to compile SAQrx. By the way, v18 is not the latest version of Portaudio but it works perfectly for basic audio I/O. v19 seems to add a lot of “bells and whistles” (and unwanted complexity...) which does not suit my QRP taste.

The FFT routine was written by Wolf DL4YHF (the author of SpecLab) and is shared with his permission.

ScopeFIR is not free but other FIR filter design programs can probably be found on the Internet.

How to compile SAQrx

1. Install the latest version of Dev-C++ (v4.9.9.2 at the time of this writing)
2. Unzip saqrx.zip into a folder of your choice
3. Double-click SAQrx.dev to open the project

You probably need to make a change in the "Project Options" because of a different directory structure on your PC (some file name paths stored in the .dev project file are relative). Most settings should be OK in my .dev file, except the path to the WMME link library. Open the “Project Options” dialog, click the tab “Parameters” and delete my old file path under “Linker”. Then click “Add Library or Object”, browse to the directory “...\lib” under the DEV-C++ installation directory and select the file libwinmm.a.

All settings under “Project Options”/Compiler should be set to “NO” except the following:
- Linker: Strip executable: YES (removes some garbage to make the .exe file smaller - QRP)
- Optimization: Perform a number fo minor optimizations: YES
- Optimization: Further Optimizations: Best Optimization: YES

Do not select a program icon in the “Project Options”! The icon is linked through a resource file.

Files in the SAQrx zip archive:

1. saqrx.dev | DEV-C++ project file
2. main.c | SAQrx main source file
3. dspmath.c | SAQrx FFT and windowing functions
4. dspmath.h | Header file for above
5. coeffs.c | SAQrx FIR filter coefficients
6. coeffs.h | Header file for above
7. saqrx.ico | SAQrx program icon
8. progicon.rc | SAQrx icon resource file
9. portaudio.h | Portaudio API (don't touch)
10. pa_convert.c | Portaudio stuff (don't touch)
11. pa_host.h | Portaudio stuff (don't touch)
12. pa_lib.c | Portaudio stuff (don't touch)
13. pa_trace.h | Portaudio stuff (don't touch)
14. pa_win_wmme.c | Portaudio stuff (don't touch)
15. saqrx.pdf | This file

Recommended reading:
Digital Signal Processing in Communication Systems
by Marvin E. Frerking, ISBN 0-442-01616-6

The Scientist and Engineer's Guide to Digital Signal Processing by Steven W. Smith, free download at www.DSPguide.com

73 de Johan Bodin, SM6LKM
Daljöfors 2006-12-30

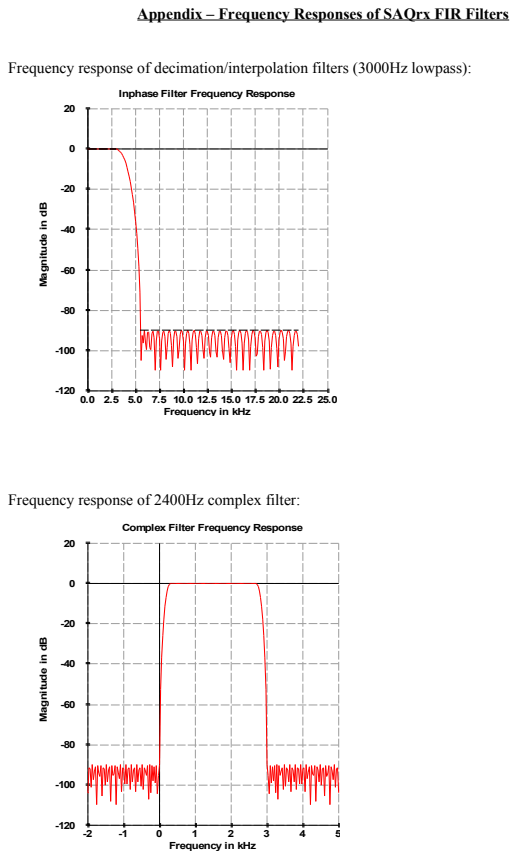
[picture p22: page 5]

Appendix – Frequency Responses of SAQrx FIR Filters

Frequency response of decimation/interpolation filters (3000Hz lowpass):

Inphase Filter Frequency Response

Magnitude in dB

Frequency in kHz

Frequency response of 2400Hz complex filter:

Complex Filter Frequency Response

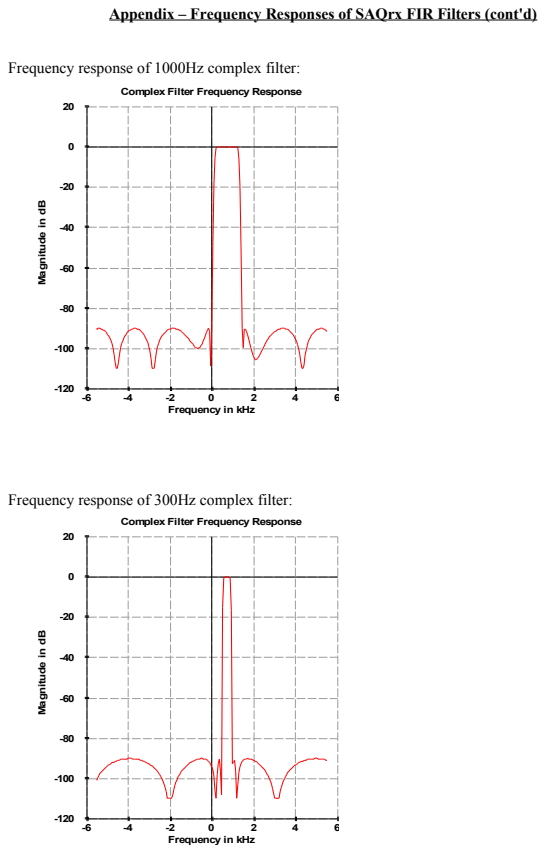
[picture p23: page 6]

Appendix – Frequency Responses of SAQrx FIR Filters (cont'd)

Frequency response of 1000Hz complex filter:

Complex Filter Frequency Response

Magnitude in dB

Frequency in kHz

Frequency response of 300Hz complex filter:

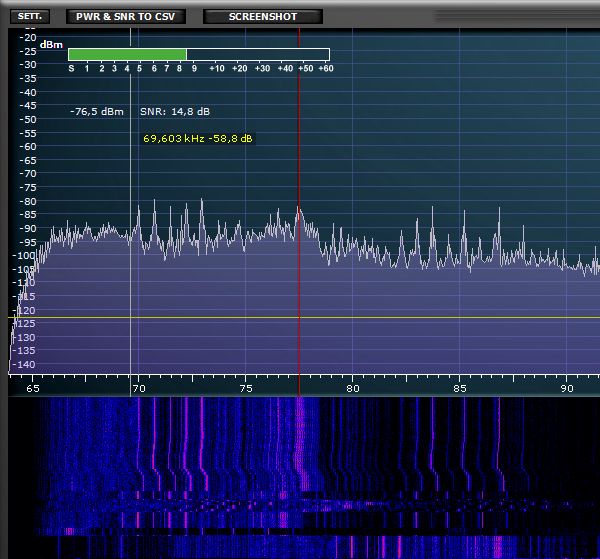
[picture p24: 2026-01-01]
img/antenna_comparison/miniwhip 2025-12-31 171257.png

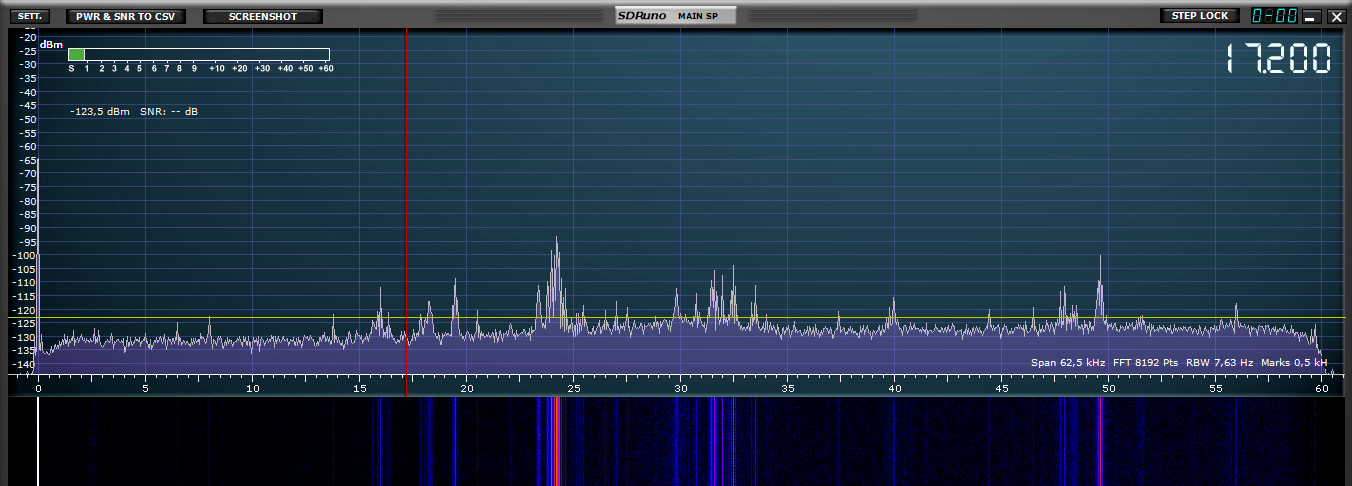
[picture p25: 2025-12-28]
img/antenna/antenna_connected_directly_to_rsp1a.png

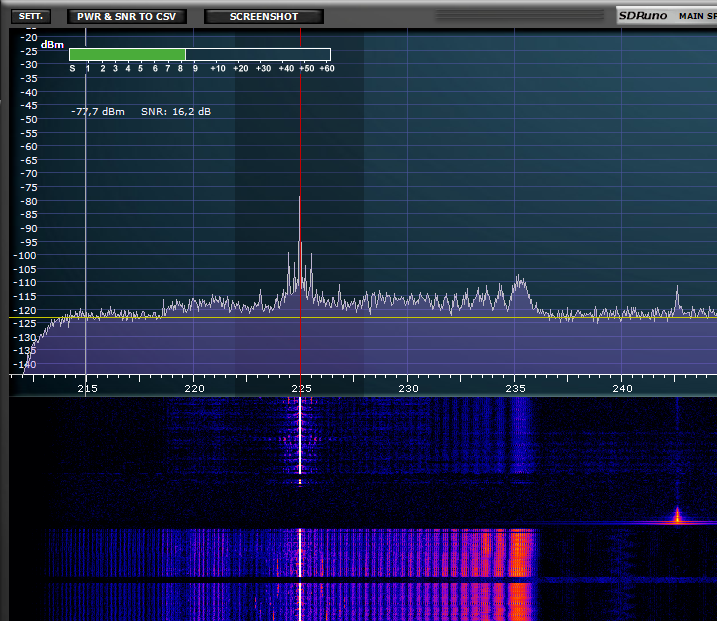
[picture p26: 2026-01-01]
img/antenna_comparison/loop_225khz 2025-12-31 171412.png

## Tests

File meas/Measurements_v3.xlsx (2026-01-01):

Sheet: Resonance_frequency
LC tank
C1 | 8.2 | nF
C2 | 0 | nF | when UTG962E frequency generator is connected directly to pre-amp input to shift resonance back to 17.2kHz, 22nF cap has to be added.
L | 10.35 | mH
f0 | 17275.99 | kHz

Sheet: Preamp_bandwidth
3dB Bandwidth Measurement for SAQ pre-amp
Setup
 |  |  |  |  |  |  | 3dB line
Arbitrary waveform generator (AWG) connected directly to primary winding instead of antenna. |  |  |  |  |  |  | f [kHz] | A[dB]
Oscilloscope connected to preamp output - it measures preamp output voltage accross 1k load resistor, which is part of the curcuit |  |  | f [kHz] | Pout[dBm] | Pout_norm[dB] |  | 1.00 | -3.00
 |  |  | 5.000 | -101.20 | -68.50 |  | 100.00 | -3.00
 |  |  | 6.000 | -95.00 | -62.30
Measurement Procedure |  |  | 7.000 | -90.00 | -57.30
 |  |  | 8.000 | -85.90 | -53.20
It is assumed that preamps input LC tank is already tuned to 17.2kHz, i.e. circuits max. observed output voltage is seen at around this frequency |  |  | 9.000 | -82.10 | -49.40
 |  |  | 10.000 | -78.80 | -46.10
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

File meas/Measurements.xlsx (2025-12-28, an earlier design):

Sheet: Arkusz1
 |  |  |  | 10.48 | mH
 |  |  |  | 4.40 | nF
in | out | ud | uf
9.63 | 8.31 | 1.32 | 0.44
11.67 | 10.31 | 1.36 | 0.45 | C[nF] | f0[kHz] |  | L[mH]
13.11 | 11.74 | 1.37 | 0.46
13.80 | 12.40 | 1.40 | 0.47 | 2.2 | 116 |  | 0.8556607364
14.66 | 13.28 | 1.38 | 0.46 | 4.4 | 79 |  | 0.9224299686
 |  |  |  | 22 | 20 |  | 2.878442717
 |  |  |  | 0.01 | 500 |  | 10.13211836 | with no cap…
 |  |  |  | 138 | 0.7079457844
 |  |  |  | 97.69651825
 |  |  |  |  |  | 4.380952381
 |  |  |  |  | 4.24291498 |  | 2.049390153

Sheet: Preamp_bandwidth
3dB Bandwidth Measurement for SAQ pre-amp
Setup
Arbitrary waveform generator (AWG) connected directly to primary winding instead of antenna. |  |  |  |  |  |  |  |  | 3dB line
Oscilloscope connected to preamp output - it measures preamp output voltage accross 1k load resistor, which is part of the curcuit |  |  |  | f [kHz] | Uppout[V] | Uppout[dBm] | Uppout/Uin [dB] | deltaUpp [dB] | f [kHz] | Uppout[V]
 |  |  |  | 2.0 | 0.13 | 42.54 | 26.98 | -25.28 | 1.00 | 1.74
 |  |  |  | 3.0 | 0.33 | 50.47 | 34.91 | -17.34 | 100.00 | 1.74
Measurement Procedure |  |  |  | 4.0 | 0.58 | 55.27 | 39.71 | -12.55
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

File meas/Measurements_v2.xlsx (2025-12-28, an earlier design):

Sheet: Resonance Calculation
 |  |  |  | 10.48 | mH
 |  |  |  | 4.40 | nF
in | out | ud | uf
9.63 | 8.31 | 1.32 | 0.44
11.67 | 10.31 | 1.36 | 0.45 | C[nF] | f0[kHz] |  | L[mH]
13.11 | 11.74 | 1.37 | 0.46
13.80 | 12.40 | 1.40 | 0.47 | 2.2 | 116 |  | 0.8556607364
14.66 | 13.28 | 1.38 | 0.46 | 4.4 | 79 |  | 0.9224299686
 |  |  |  | 22 | 20 |  | 2.878442717
 |  |  |  | 0.01 | 500 |  | 10.13211836 | with no cap…
 |  |  |  | 138 | 0.7079457844
 |  |  |  | 97.69651825
 |  |  |  |  |  | 4.380952381
 |  |  |  |  | 4.24291498 |  | 2.049390153

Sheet: Preamp_bandwidth
3dB Bandwidth Measurement for SAQ pre-amp
Setup |  |  |  |  | Uppin[mV] | 0
 |  |  |  |  | Uppin[dBm] | #NUM!
Arbitrary waveform generator (AWG) connected directly to primary winding instead of antenna. |  |  |  |  |  |  |  | 3dB line
Oscilloscope connected to preamp output - it measures preamp output voltage accross 1k load resistor, which is part of the curcuit |  |  |  |  |  |  | f [kHz] | f [kHz] | Uppout[V]
 |  |  |  |  |  |  | 16.0 | 1.00 | 1.74
 |  |  |  |  |  |  | 17.0 | 100.00 | 0.00
Measurement Procedure |  |  |  |  |  |  | 17.1
 |  |  |  |  |  |  | 17.2 | max line
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

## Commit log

2025-12-25 antenna pictures
2025-12-28 photos updated
    [Measurements.xlsx, Measurements_v2.xlsx, Measurements_v3.xlsx]
2025-12-28 antenna positioning photos added
2025-12-28 more photos added
    [saq_preamp.kicad_sch]
2026-01-01 chapter potencjalne problemy modified
    [Measurements_v3.xlsx]
2026-01-02 antenna location added
2026-01-04 final polish version
    [saq_preamp.kicad_sch]
